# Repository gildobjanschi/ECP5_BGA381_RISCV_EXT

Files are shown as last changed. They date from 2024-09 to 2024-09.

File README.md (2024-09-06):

# Extension board for ECP5_BGA381_RISCV
This is an extension board for the [ECP5_BGA381_RISCV](https://github.com/gildobjanschi/ECP5_BGA381_RISCV) board. To me it was very useful in monitoring processor is operations in terms of reading/writting registers, ROM, RAM, IO, knowing that interrupts occur, visualizing the instruction execution pipeline, cache hits and what instruction is generating a trap.

## How To setup KiCAD
Checkout the KiCAD project and open it. In the Configure Paths dialog add: Name: ECP5_BGA381_RISCV_EXT and Path: "The full path to the GitHub directory"/GitHub/ECP5_BGA381_RISCV_EXT

In the Manage Footprint Libraries click the Project Specific Libraries tab and add: Name: ECP5_BGA381_RISCV_EXT and Library Path: ${ECP5_BGA381_RISCV_EXT}/footprints/Footprints.kicad_sym

## Project Status
The board has been manufactured and it is fully verified.

[Schematic](https://github.com/gildobjanschi/ECP5_BGA381_RISCV_EXT/blob/main/kicad/ECP5_ext.pdf)

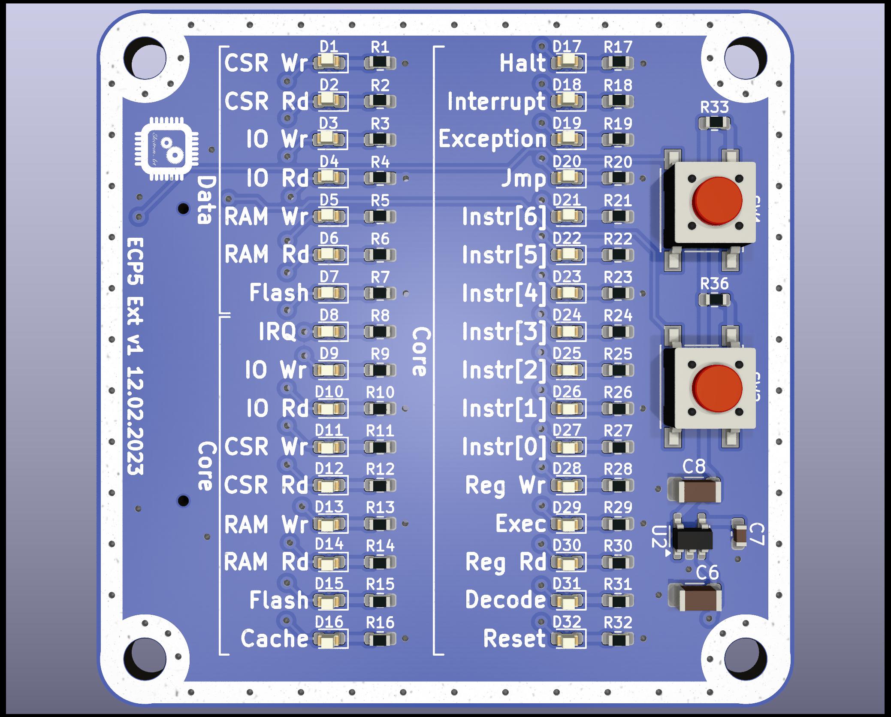
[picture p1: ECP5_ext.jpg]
Board rendering


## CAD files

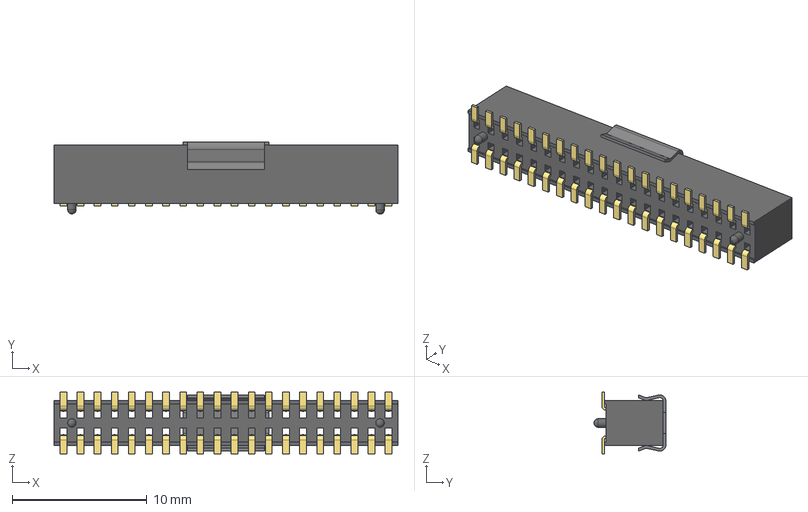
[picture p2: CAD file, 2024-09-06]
3dmodels/FLE-120-01-G-DV-A.step
25.5 x 5.33 x 4.59 mm
FLE-120-01-DV-A_socket
C-96-01-20-DV
LMP-09_pad

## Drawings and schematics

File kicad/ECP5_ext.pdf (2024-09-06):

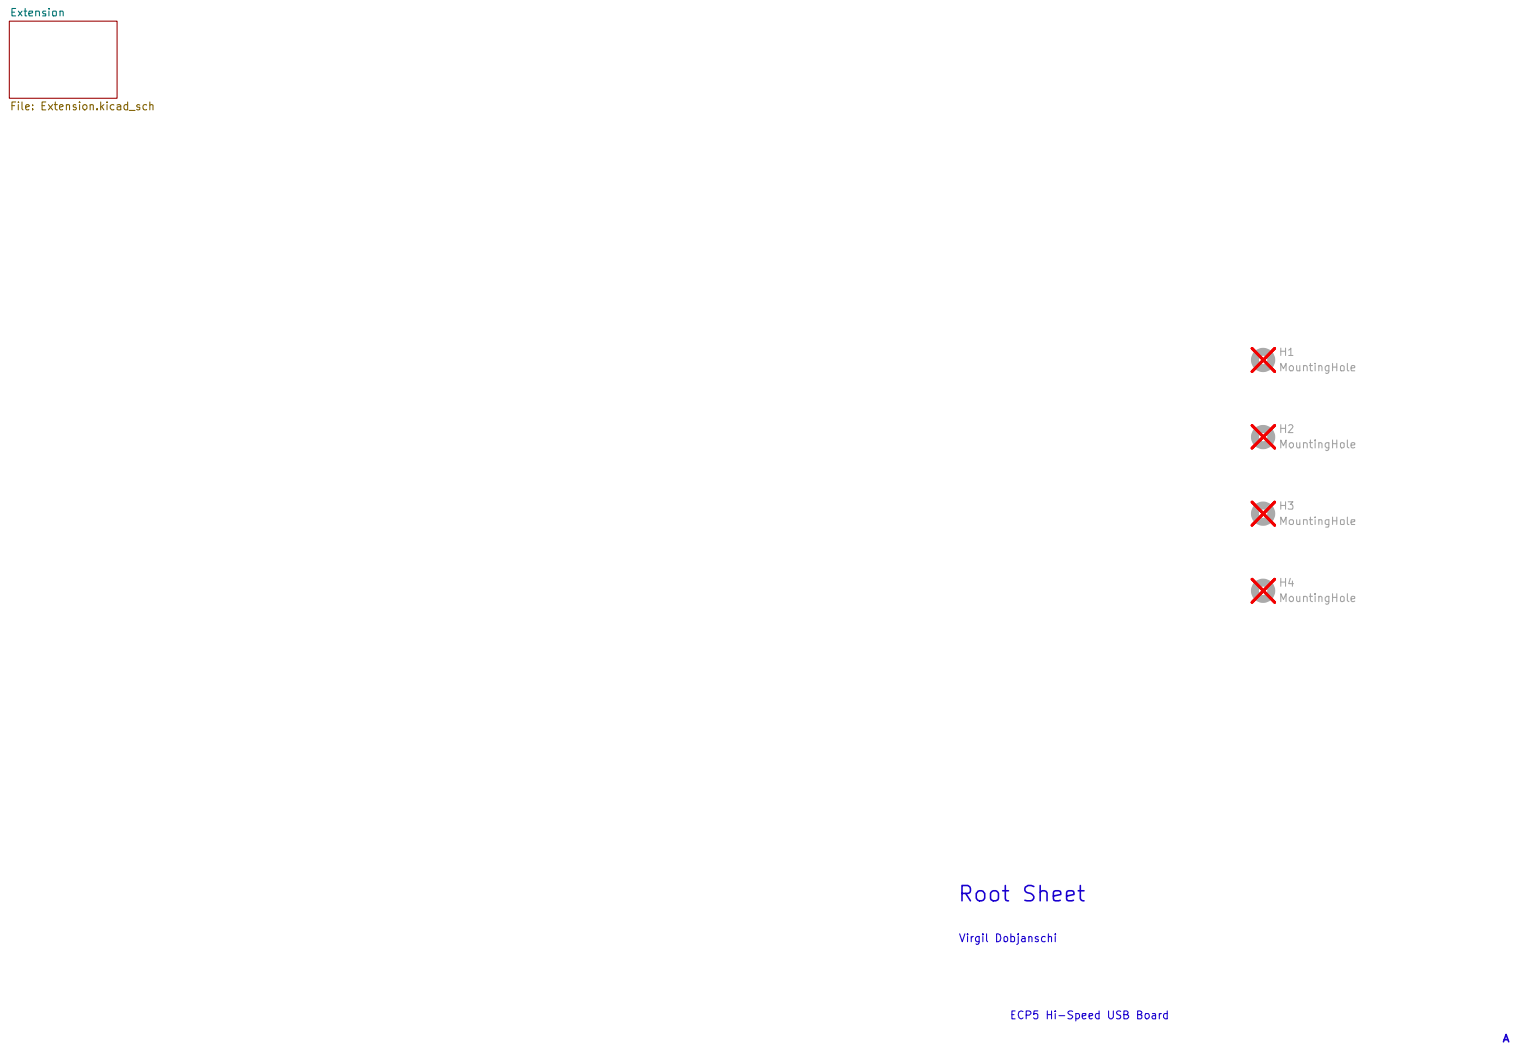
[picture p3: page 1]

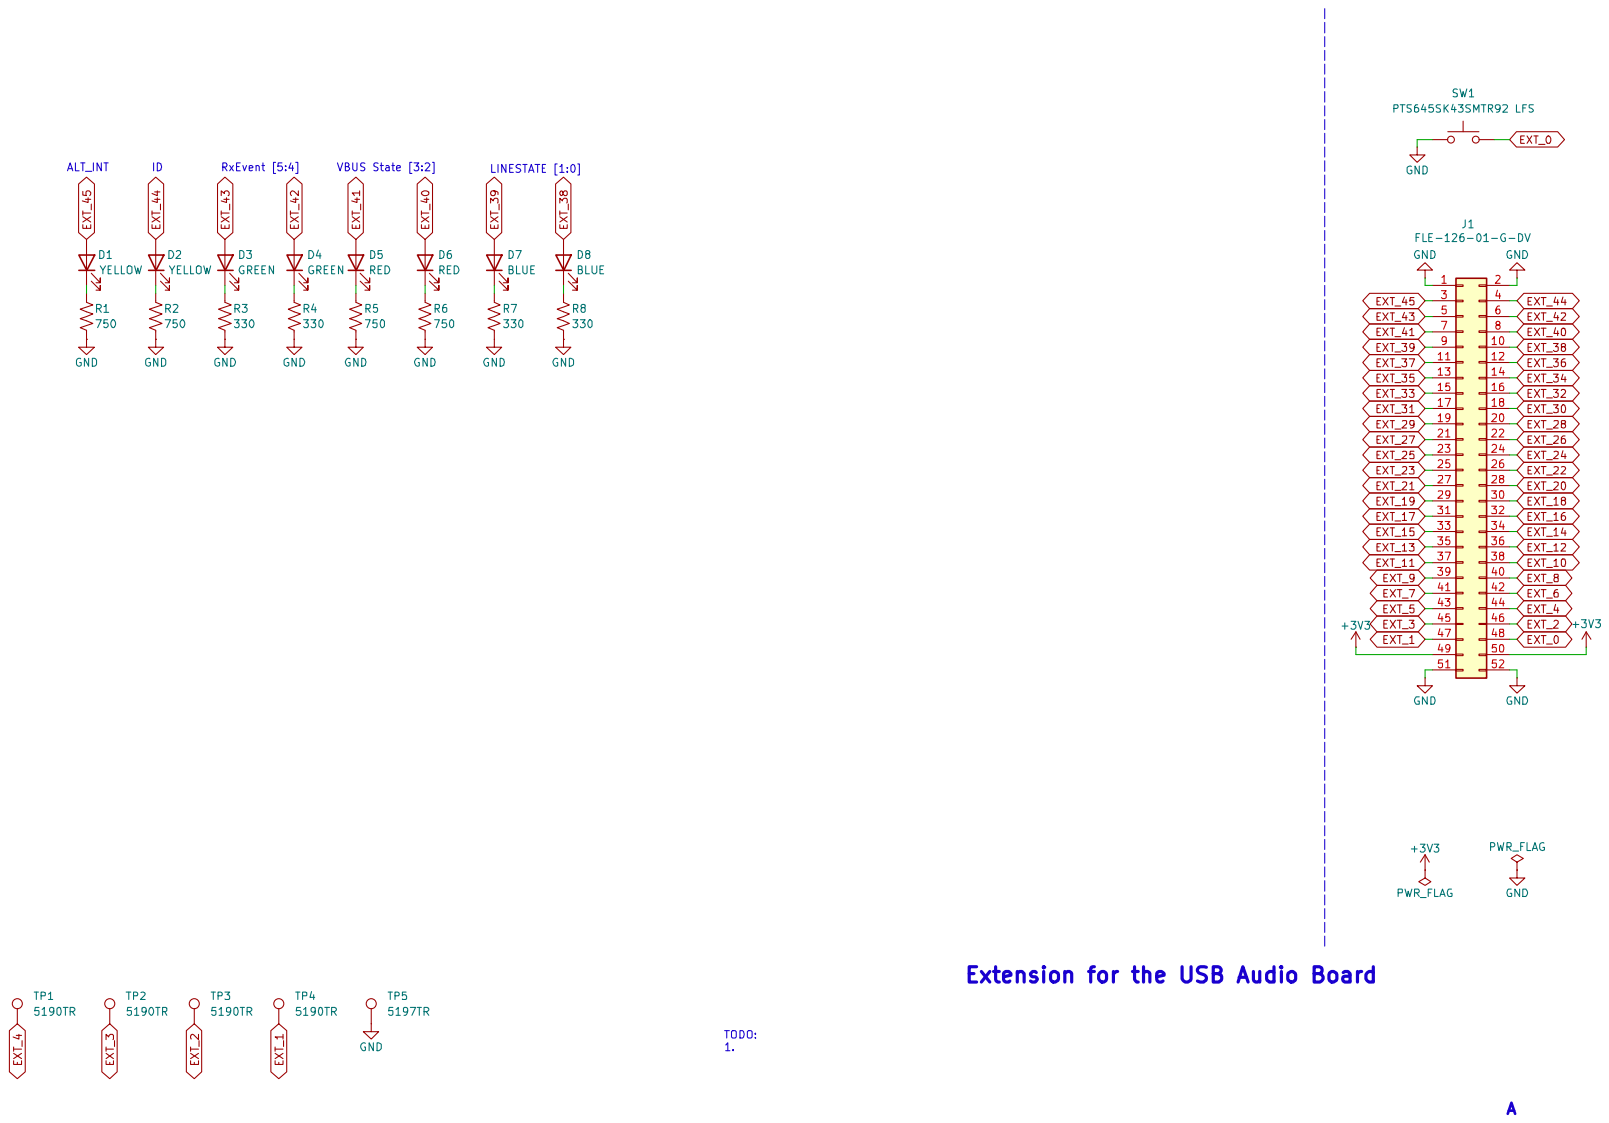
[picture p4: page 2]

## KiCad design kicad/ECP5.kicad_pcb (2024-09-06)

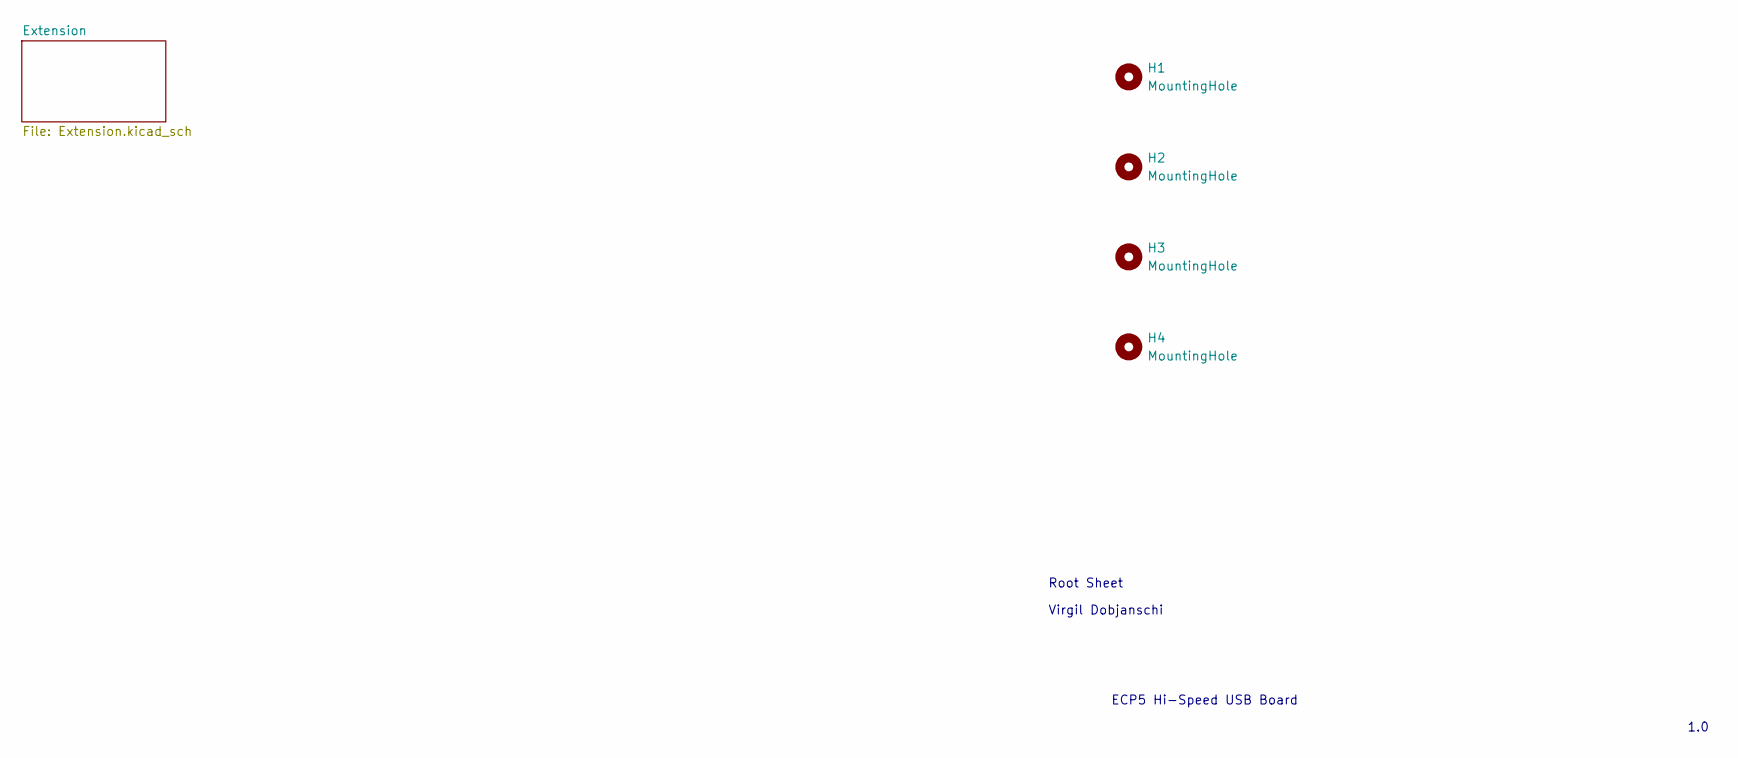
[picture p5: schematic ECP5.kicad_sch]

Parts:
H1, H2, H3, H4: MountingHole; MountingHole_3.2mm_M3

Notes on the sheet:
ECP5 Hi-Speed USB Board
Root Sheet
Virgil Dobjanschi
1.0

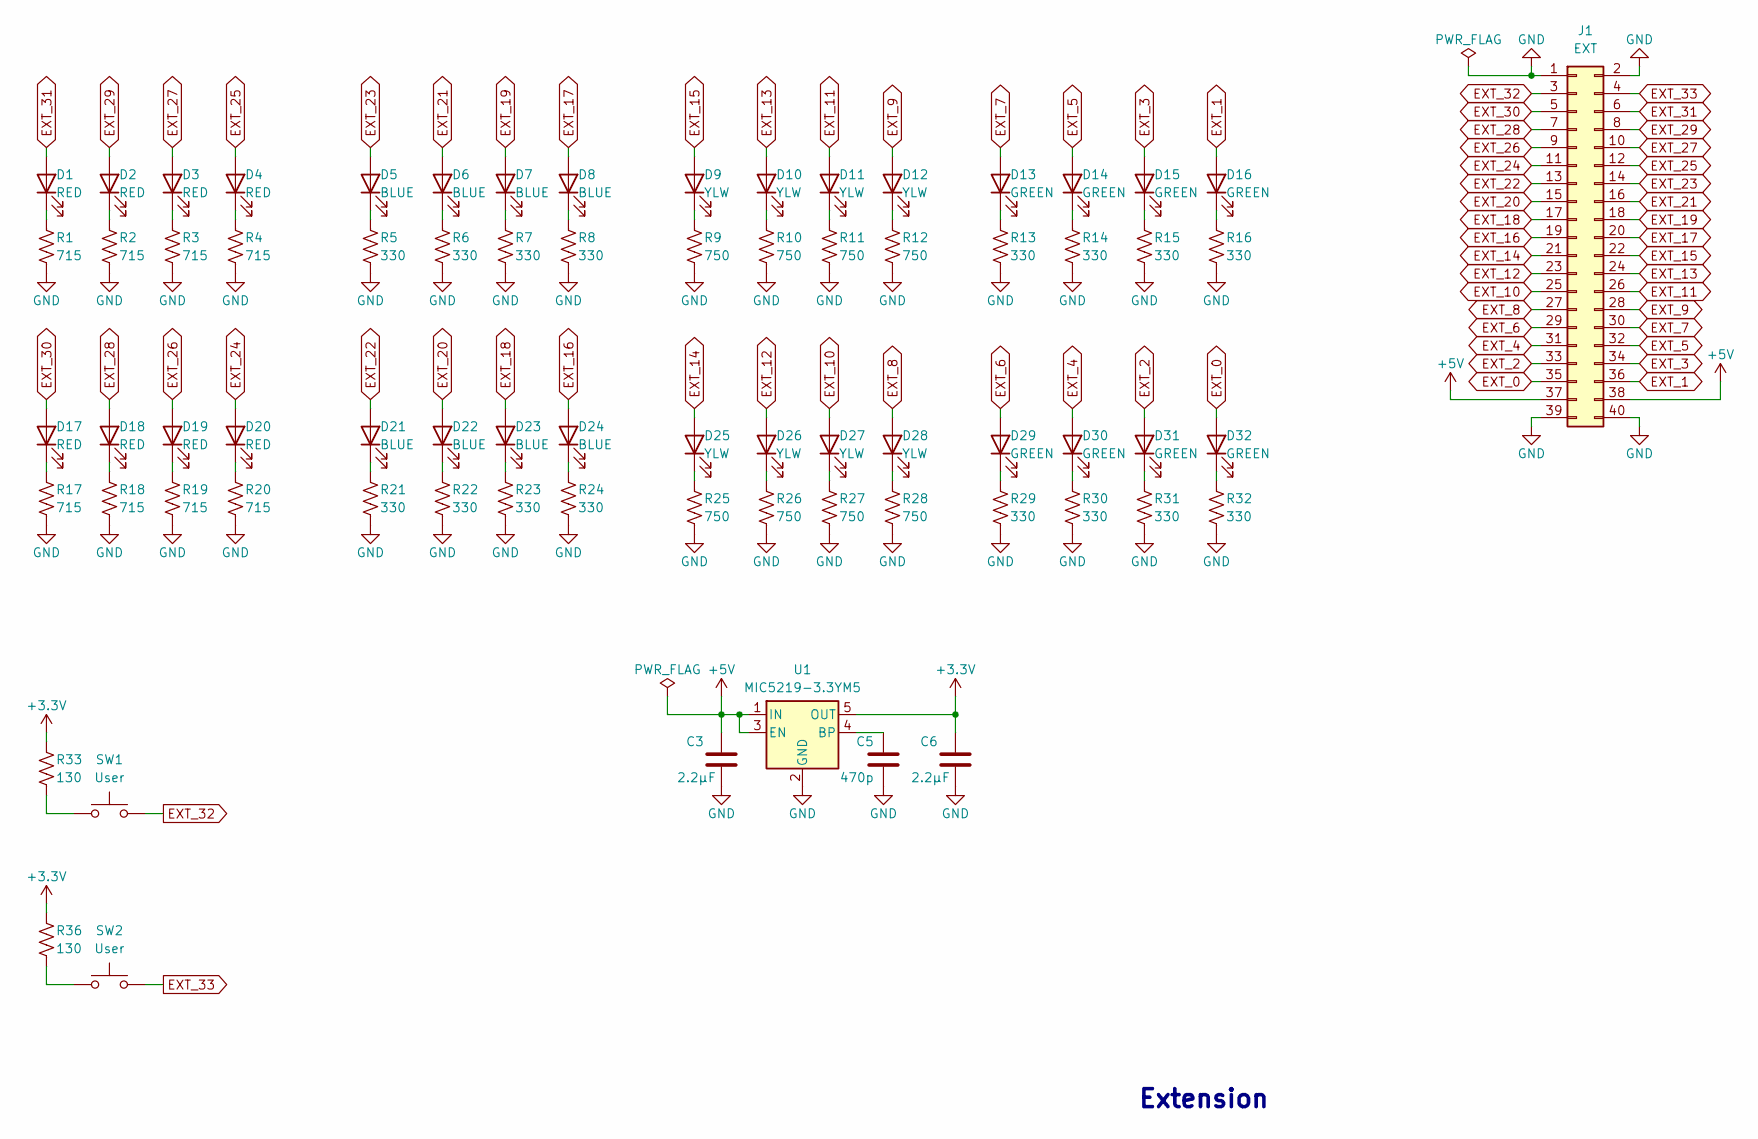
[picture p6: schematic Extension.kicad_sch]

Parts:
C3, C6: 2.2µF; C_1206_3216Metric; MPN TPSA225K010T1800
C5: 470p; C_0603_1608Metric; MPN 885012006042
D1, D2, D3, D4, D17, D18, D19, D20: RED; LED_0603_1608Metric; MPN APTD1608LSURCK
D5, D6, D7, D8, D21, D22, D23, D24: BLUE; LED_0603_1608Metric; MPN APTD1608LVBC/D
D9, D10, D11, D12, D25, D26, D27, D28: YLW; LED_0603_1608Metric; MPN APTD1608LSYCK/J3-PF
D13, D14, D15, D16, D29, D30, D31, D32: GREEN; LED_0603_1608Metric; MPN APTD1608LZGCK
J1: EXT; SAMTEC_FLE-120-01-G-DV-A; MPN FLE-120-01-G-DV-A-P-TR
R1, R2, R3, R4, R17, R18, R19, R20: 715; R_0603_1608Metric; MPN ERJ-3EKF7150V
R5, R6, R7, R8, R13, R14, R15, R16, R21, R22, R23, R24, R29, R30, R31, R32: 330; R_0603_1608Metric; MPN ERJ-3EKF3300V
R9, R10, R11, R12, R25, R26, R27, R28: 750; R_0603_1608Metric; MPN ERJ-3EKF7500V
R33, R36: 130; R_0603_1608Metric; MPN ERJ-3EKF1300V
SW1, SW2: User; SW_SPST_PTS645; MPN PTS645SM43SMTR92 LFS
U1: MIC5219-3.3YM5; SOT-23-5; MPN MIC5219-3.3YM5-TR

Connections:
EXT_0: D32.2 (A), J1.35
EXT_1: D16.2 (A), J1.36
EXT_2: D31.2 (A), J1.33
EXT_3: D15.2 (A), J1.34
EXT_4: D30.2 (A), J1.31
EXT_5: D14.2 (A), J1.32
EXT_6: D29.2 (A), J1.29
EXT_7: D13.2 (A), J1.30
EXT_8: D28.2 (A), J1.27
EXT_9: D12.2 (A), J1.28
EXT_10: D27.2 (A), J1.25
EXT_11: D11.2 (A), J1.26
EXT_12: D26.2 (A), J1.23
EXT_13: D10.2 (A), J1.24
EXT_14: D25.2 (A), J1.21
EXT_15: D9.2 (A), J1.22
EXT_16: D24.2 (A), J1.19
EXT_17: D8.2 (A), J1.20
EXT_18: D23.2 (A), J1.17
EXT_19: D7.2 (A), J1.18
EXT_20: D22.2 (A), J1.15
EXT_21: D6.2 (A), J1.16
EXT_22: D21.2 (A), J1.13
EXT_23: D5.2 (A), J1.14
EXT_24: D20.2 (A), J1.11
EXT_25: D4.2 (A), J1.12
EXT_26: D19.2 (A), J1.9
EXT_27: D3.2 (A), J1.10
EXT_28: D18.2 (A), J1.7
EXT_29: D2.2 (A), J1.8
EXT_30: D17.2 (A), J1.5
EXT_31: D1.2 (A), J1.6
EXT_32: J1.3, SW1.2
EXT_33: J1.4, SW2.2
GND: C6.2, J1.1, J1.2, J1.39, J1.40, R1.2, R2.2, R3.2, R4.2, R5.2, R6.2, R7.2, R8.2, R9.2, R10.2, R11.2, R12.2, R13.2, R14.2, R15.2, R16.2, R17.2, R18.2, R19.2, R20.2, R21.2, R22.2, R23.2, R24.2, R25.2, R26.2, R27.2, R28.2, R29.2, R30.2, R31.2, R32.2; also elsewhere on the board
unnamed: D1.1 (K), R1.1
unnamed: D2.1 (K), R2.1
unnamed: D3.1 (K), R3.1
unnamed: D4.1 (K), R4.1
unnamed: D5.1 (K), R5.1
unnamed: D6.1 (K), R6.1
unnamed: D7.1 (K), R7.1
unnamed: D8.1 (K), R8.1
unnamed: D9.1 (K), R9.1
unnamed: D10.1 (K), R10.1
unnamed: D11.1 (K), R11.1
unnamed: D12.1 (K), R12.1
unnamed: D13.1 (K), R13.1
unnamed: D14.1 (K), R14.1
unnamed: D15.1 (K), R15.1
unnamed: D16.1 (K), R16.1
unnamed: D17.1 (K), R17.1
unnamed: D18.1 (K), R18.1
unnamed: D19.1 (K), R19.1
unnamed: D20.1 (K), R20.1
unnamed: D21.1 (K), R21.1
unnamed: D22.1 (K), R22.1
unnamed: D23.1 (K), R23.1
unnamed: D24.1 (K), R24.1
unnamed: D25.1 (K), R25.1
unnamed: D26.1 (K), R26.1
unnamed: D27.1 (K), R27.1
unnamed: D28.1 (K), R28.1
unnamed: D29.1 (K), R29.1
unnamed: D30.1 (K), R30.1
unnamed: D31.1 (K), R31.1
unnamed: D32.1 (K), R32.1
unnamed: R33.2, SW1.1
unnamed: R36.2, SW2.1

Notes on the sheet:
Extension

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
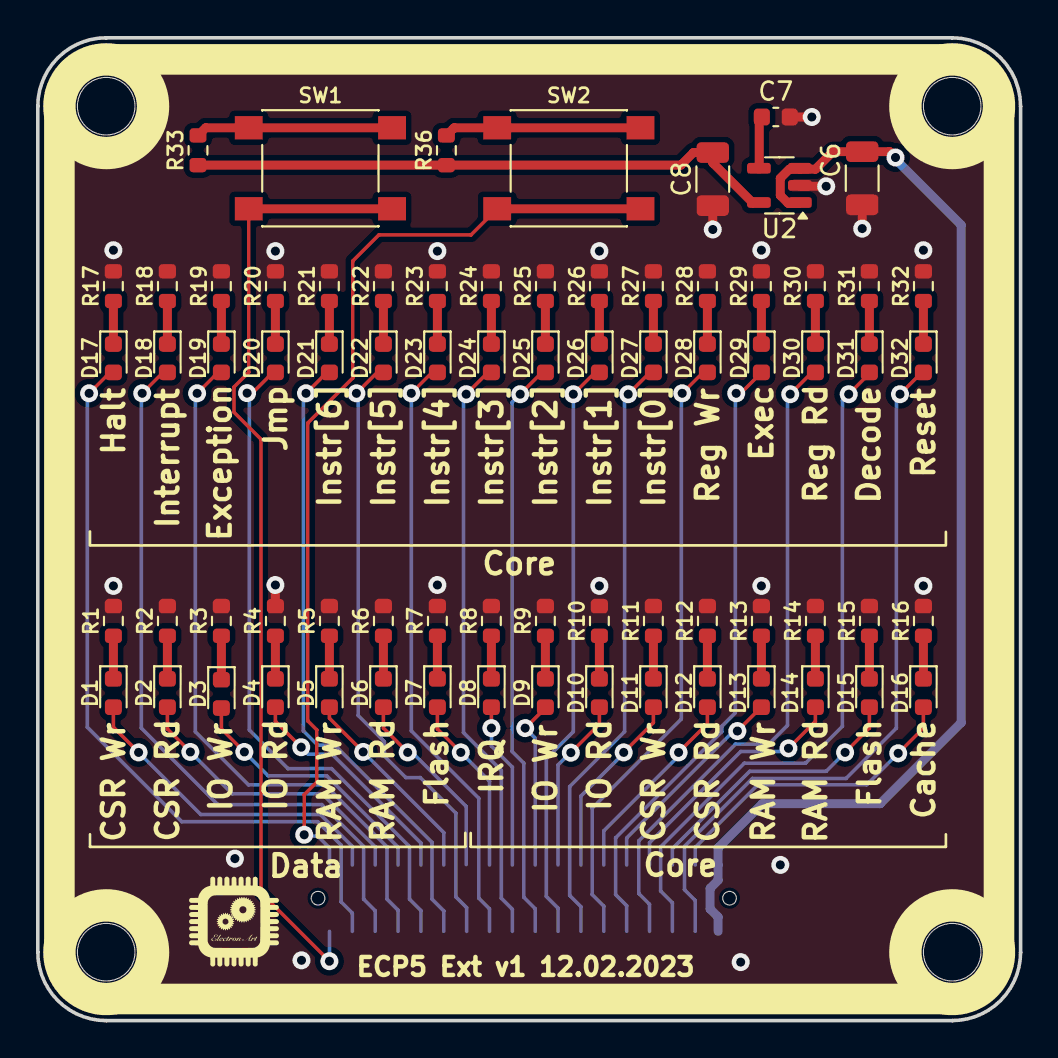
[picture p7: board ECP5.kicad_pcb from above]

Board: 4 copper layers, 54.6 x 54.6 mm, 77 parts (1 on the bottom side), 72 nets.

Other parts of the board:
C7: 470p; C_0603_1608Metric
C8: 2.2µF; C_1206_3216Metric
U2: MIC5219-3.3YM5; SOT-23-5

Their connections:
GND: C7.2, C8.2, U2.2 (GND); also elsewhere on the board
unnamed: C7.1, U2.4 (BP)

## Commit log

2024-09-06 First checkin
    [ECP5.kicad_pcb, ECP5.kicad_sch, Extension.kicad_sch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]
2024-09-06 Added schematic PDF

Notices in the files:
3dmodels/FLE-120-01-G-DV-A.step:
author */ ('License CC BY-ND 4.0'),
